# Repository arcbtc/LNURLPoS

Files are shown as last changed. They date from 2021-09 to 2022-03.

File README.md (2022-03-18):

# LNURLPoS

## Cheap, offline(!), DIY bitcoin lightning-network PoS

### for a more up to date version of lnurlpos, checkout <a href="https://github.com/arcbtc/bitcoinPoS">bitcoinPoS</a>

lnurlpos

Lightning-network uses hot wallets and real-world payments are made from phones. The burden of connectivity can be taken away from the point-of-sale and given to the phone.



> <i>Join our <a href="https://t.me/makerbits">telegram support/chat</a>.</i>

> <i>For a traditional PoS experience see my <a href="https://github.com/arcbtc/LNPoS">LNPoS project</a>.</i>

> <i>The manufacturer of the microcontroller used have actually released a specific kit for LNURLPoS! <a href="https://github.com/Xinyuan-LilyGO/T-Display-keyboard">LiLyGos repo</a>.</i>

LNURLPoS uses the LNURL-pay protocol. LNURL-pay allows your lightning-wallet to make a secure request to a server to get a lightning-network invoice. So instead of scanning a massive ugly lightning-network invoice QR, you can scan a lovely little LNURL QR (if you <a href="https://lnurl.fiatjaf.com/codec/">decode</a> an LNURL you'll see its just a URL).



For online stuff I suppose massive QR codes are not an issue, but when fiddling with hardware devices they are. LNURLPoS using the LNURL-pay protocol, it can use a smaller screen for displaying the QR.

### Setup workflow

- LNURLPoS server set up and register PoS in a few clicks on <a href="https://github.com/lnbits/lnbits/">LNbits</a> using the <a href="https://github.com/lnbits/lnbits/tree/master/lnbits/extensions/lnurlpos">LNURLPoS</a> extension
- Copy credentials (including a secret key) from server to the physical LNURLPoS device

### Payment workflow

- Merchant enters amount into LNURLPoS device
- LNURL is generated in device and displayed for scanning (LNURL includes a unique pin encrypted using the secret key shared with the server)
- Customer scans and pays
- When the payment has cleared the customer is sent the decrypted unique pin
- Merchant can compare and verify using the same pin displayed on the lNURLPoS

### Credit/props

Stepan Snigerev for creating beautiful crypto and LNURL encoding functions.

Fiatjafs incredible <a href="https://github.com/lnbits/lnbits/tree/master/lnbits/extensions/offlineshop">OfflineShop</a> extension. LNURLPoS is the same concept, but can run at scale, and is dependent on a device.

<a href="https://www.bleskomat.com/">Belskomat</a> for pironeering the idea of a shared secret for the microcontroller to encrypt data with.

# ⚡⚡⚡⚡⚡⚡ LNURLPoS Tutorial ⚡⚡⚡⚡⚡⚡



### Hardware needed

- <a href="https://www.aliexpress.com/item/33048962331.html">Lilygo TTGO T-Display</a>
- Keypad membrane (these <a href="https://www.aliexpress.com/item/32812109541.html">big</a> ones are easy to find, these <a href="https://www.aliexpress.com/item/1005003263865347.html">smaller</a> ones will be used for workshops by arcbtc).
- <a href="https://www.amazon.co.uk/Sourcingmap-2x40-Pins-Connector-Arduino-Prototype-Black-Silver-Tone/dp/B07DK532DP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">Angled male/male GPIO pins</a>

### Arduino software install

- Download/install latest <a href="https://www.arduino.cc/en/software">Arduino IDE</a>
- Install ESP32 boards, using <a href="https://docs.espressif.com/projects/arduino-esp32/en/latest/installing.html#installing-using-boards-manager">boards manager</a>
- Copy <a href="https://github.com/arcbtc/LNURLPoS/tree/main/LNURLPoS/libraries">these libraries</a> into your Arduino IDE library folder
- Plug in T-Display, from _Tools>Board>ESP32 Boards_ select **TTGO LoRa32 OLED V1**

> _Note: If using MacOS, you will need the CP210x USB to UART Bridge VCP Drivers available here https://www.silabs.com/developers/usb-to-uart-bridge-vcp-drivers_

### LNbits extension

To make things easy (usually a few clicks on things like Raspiblitz), there is an <a href="https://github.com/lnbits/lnbits/tree/master/lnbits/extensions/lnurlpos">LNbits extension</a>.
If you want to make your own stand-alone server software that would be fairly easy to do, by replicating the lnurl.py file in the extennsion.

### Future updates

At the beginning of this article I said "LNURLPoS (currently) only uses LNURL-Pay". The next stage will be for the PoS to also create LNURL-Withdraws, which are essentially faucets. This means merchants can offer refunds, and also sell bitcoin over the counter, which creates an extremely powerful tool for local economies on-ramping and off-ramping from their local fiat currency.

At Adopting Bitcoin in San Salvador I will distribute 40 kits over x2 workshops, so hopefully some locals will start producing, selling and teaching others how to make these useful little units.

---

## Deeper Dive

### LNURL

Much of the innovation that happens on lightning-network uses an additional protocol layer called LNURL.

LNURL is just a bech32 encoded URL string, that is a link to an LNURL server that your lightning wallet can request information from. By your wallet being able to communicate with a server, developers are no longer bound by the _payee-generate-invoice_ workflow. There are many different types of LNURL. LNURLPoS (currently) only uses LNURL-Pay.

This is an LNURL-pay QR code:



This is the data in that QR code:

`LNURL1DP68GURN8GHJ7MRWVF5HGUEWVDHK6TMVDE6HYMRS9ASHQ6F0WCCJ7MRWW4EXCTECXVUQR8PUDZ`

If we decode the LNURL we get this URL:

`https://legend.lnbits.com/lnurlp/api/v1/lnurl/838`

If you do a GET request to the URL this data will be returned (you can test this by just visiting the URL in a browser):

```
{
  "callback": "https://lnbits.com/lnurlp/api/v1/lnurl/cb/838",
  "maxSendable": 10000000000,
  "metadata": "[[\"text/plain\", \"Lovely little QR\"]]",
  "minSendable": 10000,
  "tag": "payRequest"
}
```

When your wallet gets this json it asks you how much you want to send between the `minSendable` and `maxSendable`.

After a moment you get a “payment sent” confirmation and receipt.



So what happened?

When you verify you want to send say 10sats, your wallet sends that data (as a json) to the `callback` URL. The server then generates an invoice for that amount and sends it back to your wallet, which pays it. Once the payment has cleared, the wallet reveals a receipt to you.

### LNURLPoS workflow

LNURLPoS generates and encodes the LNURL in the device, which means we can pass some data in the URL.

The LNURLPoS stores four important pieces of data:

- URL to your LNURL server (we’re using an LNbits install, with dedicated extension)
- PoS ID (Unique ID generated in the LNbits extension)
- Secret (Secret shared with the LNURL server)
- Currency denomination (being offline sats becomes too volatile)

LNURLPoS could use any LNURL server that performs some certain functions, but to make things easy I made an extension in LNbits specifically for LNURLPoS




Once a PoS has been generated the extension gives you this data:

```
String server = "https://lnbits.com";
String posId = "L4aJNiQZyPxCREoB3KXiiU";
String key = "4TPLxRmv82yEFjUgWKdfPh";
String currency = "EUR";
```

The data can then be passed to the device when uploading its software through the Arduino IDE



When an amount is entered into the LNURLPoS, the device generates a unique pin, then encrypts the amount+pin using the shared secret and a nonce. The server endpoint, nonce, encypted data, and PoS ID are built into into the LNURL.

`https://lnbits.com/lnurlpos/api/v1/lnurl/<nonce>/<encrypted-data>/<pos-id>`

`LNURL1DP68GURN8GHJ7MRWVF5HGUEWVDHK6TMVDE6HYMRSDAEJ7CTSDYHHVVF0D3H82UNV9U7XUMMWVDJNUTEUV4HXXUNEWP6X2EPDV3SHGCF79U78QMMN945KG0S2PG6GTWSK`

When that first GET request happens from the wallet, the LNURL server can find the PoS record, fetch its secret use the secret to decrypt the amount+pin. The amount is converted from the fiat currency to sats, and sent back to the wallet as `minSendable` and `maxSendable`.

If the invoice passed to the wallet is paid the customer is given access to the decrypted pin.



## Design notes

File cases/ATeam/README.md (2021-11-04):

## ATeam Edition case
Recycle the T-Display case, as with the smaller keypad it all fits together perfectly. See <a href="https://twitter.com/arcbtc/status/1442511015669809152">demo</a>

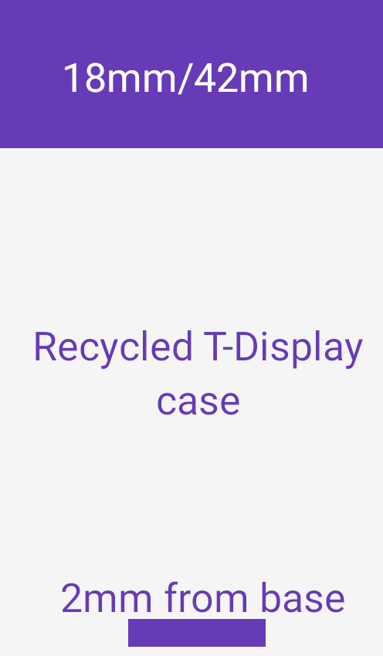
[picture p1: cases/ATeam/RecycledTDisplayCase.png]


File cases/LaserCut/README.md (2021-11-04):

## Laser Cut CAses for LNURLPoS

There are 2 lightburn designs for cases depending on membrane keypads. Designs use layered 3mm acrylic and M4 nuts/bolts <br/>(Blue = fill/engrave 1.5mm depth, Black = cut)

<p align="center">

</p>
<br/><br/>
Laser cutters are cheap now and should be part of every makers arsenal, these examples were cut on £200 NEJE Master2s 20W, alternatively there are plenty of laser engraving/cutting companies.
<br/><br/>

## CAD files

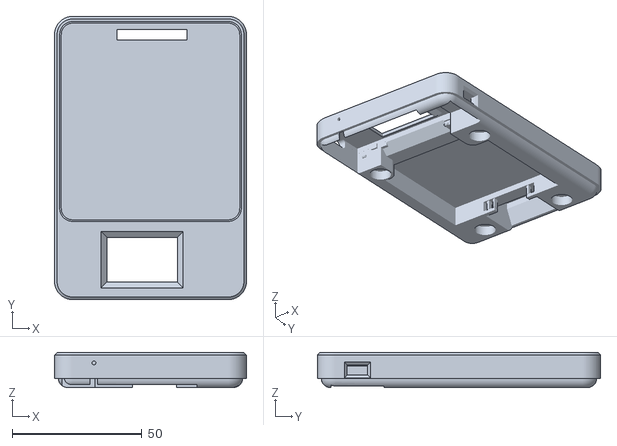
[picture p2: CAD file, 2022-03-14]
cases/3d printed/4 x 4 keypad/LNURLPoS case top with supports.stl
74.0 x 109.1 x 13.5

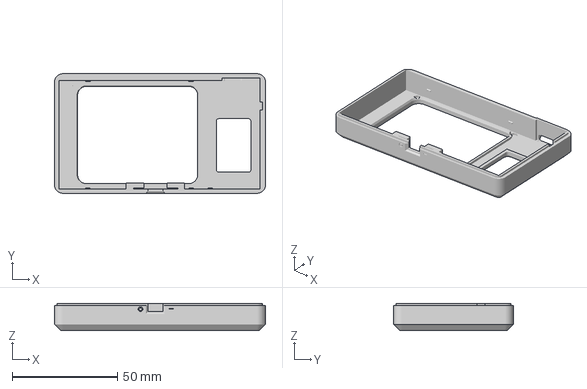
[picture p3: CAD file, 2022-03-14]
cases/3d printed/LilyGo T-Display Keyboard/LilyGo keyboard case top larger hole.3mf
100.2 x 56.8 x 13.0 mm

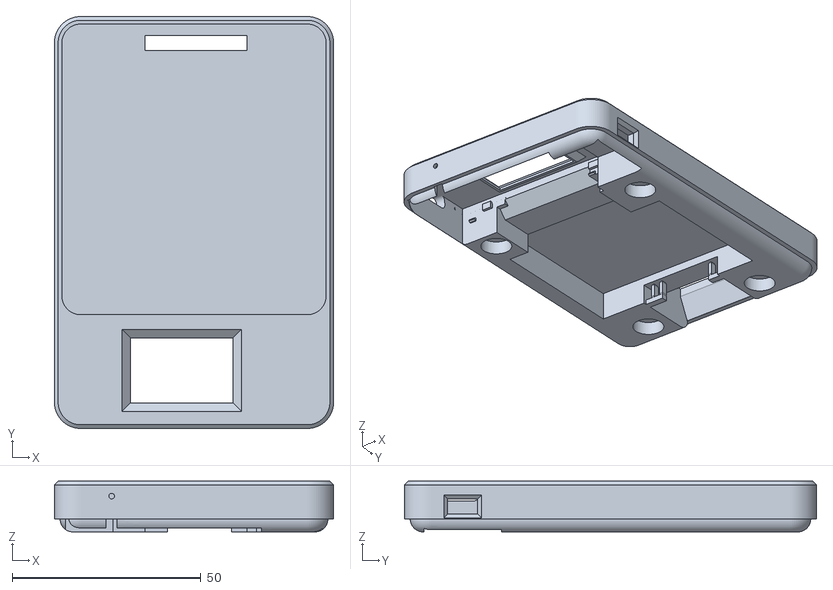
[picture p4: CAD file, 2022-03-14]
cases/3d printed/4 x 4 keypad/LNURLPoS case top.stl
74.0 x 109.1 x 13.5

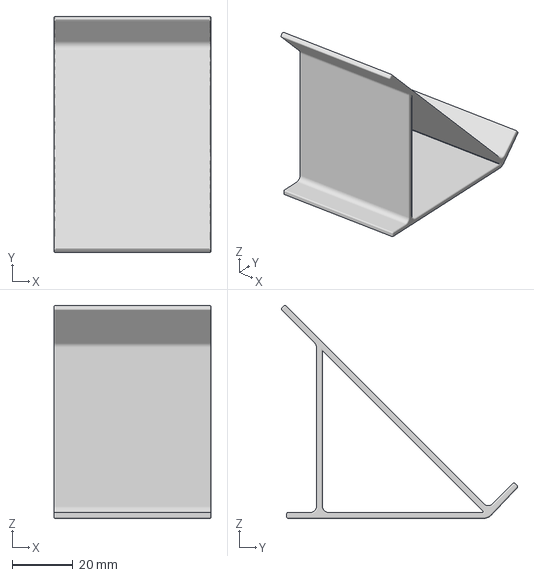
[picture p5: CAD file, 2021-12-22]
cases/3d printed/LilyGo T-Display Keyboard/Stand.3mf
51.7 x 77.9 x 70.2 mm

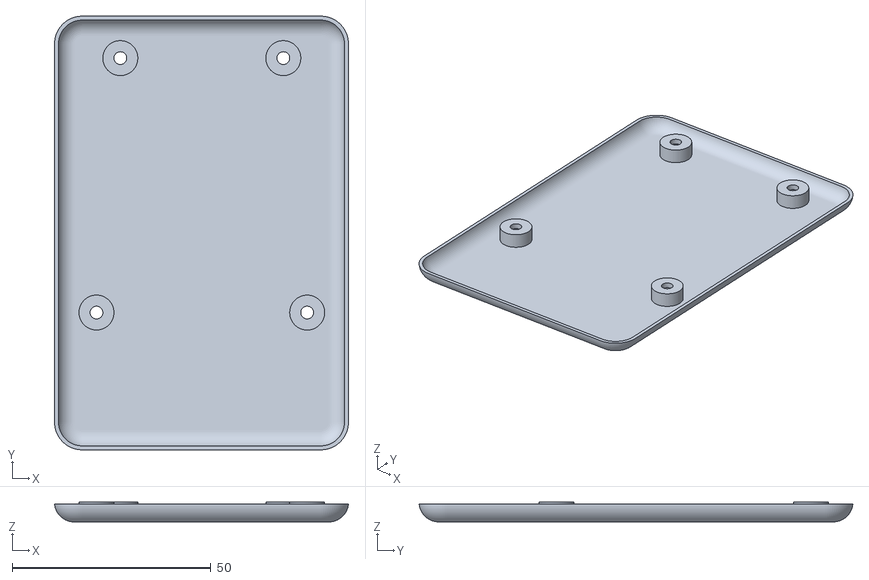
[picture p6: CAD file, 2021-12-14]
cases/3d printed/4 x 4 keypad/LNURLPoS case bottom.stl
73.9 x 109.1 x 5.00

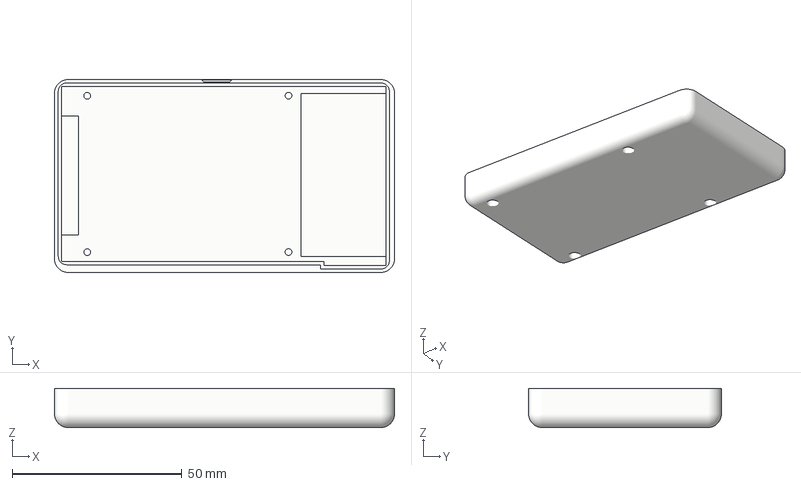
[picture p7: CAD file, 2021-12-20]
cases/3d printed/LilyGo T-Display Keyboard/LilyGo keyboard case bottom.3mf
100.2 x 56.9 x 11.5 mm

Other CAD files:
cases/3d printed/LilyGo T-Display Keyboard/LilyGo keyboard case top.3mf

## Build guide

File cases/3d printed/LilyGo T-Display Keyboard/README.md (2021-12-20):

# 3D Printed Cases for LNURLPoS with LilyGo T-Display Keyboard

These 3D print files will print a case for the LilyGo T-Display Keyboard https://aliexpress.com/item/1005003534734992.html.

The keyboard will need to be dismantled to fit it into the case.

When reassembling, the screws that held the back plate on to the keyboard, go through the back of the case as well as the keyboard rear plate to hold the case together.

Use these switches if you want to include a battery for untethered power https://www.amazon.co.uk/gp/product/B00OK9FAUW/

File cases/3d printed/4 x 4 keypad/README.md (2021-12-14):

# 3D Printed Cases for LNURLPoS

These 3D print files will print a case for the LNURLPoS device

There is space inside the case for a small battery, a switch and the TTGO display.

These switches will fit in the case. They should be hot glued into place until we have a better solution.

https://www.amazon.co.uk/gp/product/B00OK9FAUW/

## Printing

The stl/m3u files print best when oriented with the keypad side of the top and the outside of the bottom flat on the print bed. 

Use printing support everywhere with 20% infil.

## Additional Parts

4 x M3 x 5mm screws are required to attach the base to the top.

4 x 5.6mm adhesive rubber feet stop the case sliding around on a work surface - https://www.ebay.co.uk/itm/192563250638

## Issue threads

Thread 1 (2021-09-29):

'QRCode' was not declared in this scope?

HamishMacEwan, 2021-09-29:
Hi,

I've checked that I followed the instructions and I have Googled for this error, but none of the results seem conclusive or apply.

It's my first time with the Arduino IDE, but it seems to have found and I've installed the libraries required, and though I'm still waiting for the hardware, thought I'd get about preparing for its arrival by verifying, by compilation, the set up.

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

If there's any additional information required, please advise.

arcbtc, 2021-09-29:
Thanks Hamish!
You need to copy the libraries into you arduino core libraries folder.
Open File>Examples>Basic>Blink
Go to Sketch>Show sketch foler
Now you have your Arduino install folder, go down a few levels
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
Then place the projects libraries in the core libraries folder:
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
Should be gravy now!

HamishMacEwan, 2021-09-29:
Thanks very much for the instructions.  It has led to a long and frustrating encounter with Windows 10 permissions.

The directory for the installation as derived from your guidance above is:

`C:\Program Files\WindowsApps\ArduinoLLC.ArduinoIDE_1.8.51.0_x86__mdqgnx93n4wtt\libraries`

All attempts to copy the files there have been met with refusal and my permissions foo has not been very successful, though I do now "own" the WindowsApps folder, to no useful effect.

Currently I have the additional libraries in a more accessible folder and for all but the QRCode library that appears to be working:

```
Using library SPI at version 2.0.0 in folder: C:\Users\User\OneDrive\Documents - Old\ArduinoData\packages\esp32\hardware\esp32\2.0.0\libraries\SPI

Using library TFT_eSPI at version 2.2.20 in folder: C:\Users\User\OneDrive\Documents - Old\Arduino\libraries\TFT_eSPI

Using library FS at version 2.0.0 in folder: C:\Users\User\OneDrive\Documents - Old\ArduinoData\packages\esp32\hardware\esp32\2.0.0\libraries\FS

Using library SPIFFS at version 2.0.0 in folder: C:\Users\User\OneDrive\Documents - Old\ArduinoData\packages\esp32\hardware\esp32\2.0.0\libraries\SPIFFS

Using library Keypad at version 3.1.1 in folder: C:\Users\User\OneDrive\Documents - Old\Arduino\libraries\Keypad

Using library uBitcoin at version 0.1.2 in folder: C:\Users\User\OneDrive\Documents - Old\Arduino\libraries\uBitcoin
```

There is a collision at:
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

That is another `qrcode.h` at `C:\Users\User\OneDrive\Documents - Old\ArduinoData\packages\esp32\hardware\esp32\2.0.0\tools\sdk\esp32\include\qrcode\include` which is fulfilling the `#include` though not usefully.

Is there are way to specify exactly the order of paths to search or include a path in the `#include` syntax?

babysnakeum, 2021-10-01:
FYI I'm observing the same issue on mac, even after copying the libraries into arduinos core libraries folder

HamishMacEwan, 2021-10-02:
```
Arduino: 1.8.16 (Windows 10), Board: "TTGO LoRa32-OLED V1, 80MHz, 921600, None"

c:/users/user/appdata/local/arduino15/packages/esp32/tools/xtensa-esp32-elf-gcc/gcc8_4_0-esp-2021r1/bin/../lib/gcc/xtensa-esp32-elf/8.4.0/../../../../xtensa-esp32-elf/bin/ld.exe: C:\Users\User\AppData\Local\Arduino15\packages\esp32\hardware\esp32\2.0.0/tools/sdk/esp32/lib\libwpa_supplicant.a(crypto_mbedtls.c.obj): in function `hmac_sha256':

/home/runner/work/esp32-arduino-lib-builder/esp32-arduino-lib-builder/esp-idf/components/wpa_supplicant/src/crypto/crypto_mbedtls.c:254: multiple definition of `hmac_sha256'; libraries\uBitcoin\utility\trezor\hmac.c.o:C:\Program Files (x86)\arduino-1.8.16\libraries\uBitcoin\src\utility\trezor/hmac.c:67: first defined here

collect2.exe: error: ld returned 1 exit status

exit status 1

Error compiling for board TTGO LoRa32-OLED V1.
```

Different error, so one thing is solved.

ShelbyApp, 2021-11-08:
I've put the QRCode library in every libraries folder that exists and still have this problem.

I can even click Sketch->Include Library->QRCode which includes <qrcode.h> and still get the problem

I can access the QRCode example through the Arduino software and that won't compile either (Same error)

Seems like there is a bigger problem going on?

citizenanalog, 2021-11-08:
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

I had to switch to MacOS and had to add the libraries manually but eventually got it to work. Still no luck on Ubuntu.

ShelbyApp, 2021-11-08:
I moved the QRCode to the local folder with "qrcode.h" and got it to work

but now I am getting the redundant sha256 error now  :(  Did you have that one?

c:/users/jason/appdata/local/arduino15/packages/esp32/tools/xtensa-esp32-elf-gcc/gcc8_4_0-esp-2021r1/bin/../lib/gcc/xtensa-esp32-elf/8.4.0/../../../../xtensa-esp32-elf/bin/ld.exe: C:\Users\Jason\Documents\Arduino\hardware\espressif\esp32/tools/sdk/esp32/lib\libwpa_supplicant.a(crypto_mbedtls.c.obj): in function `hmac_sha256':

/Users/ficeto/Desktop/ESP32/ESP32S2/esp-idf-public/components/wpa_supplicant/src/crypto/crypto_mbedtls.c:254: multiple definition of `hmac_sha256'; libraries\uBitcoin\utility\trezor\hmac.c.o:C:\Program Files (x86)\Arduino\libraries\uBitcoin\src\utility\trezor/hmac.c:67: first defined here
collect2.exe: error: ld returned 1 exit status

ShelbyApp, 2021-11-08:
DING DING DING

If you go to utilities/trezor/hmac.c

There are 2 definitions of the following, just delete 1 and should be good to go

void hmac_sha256(const uint8_t *key, const uint32_t keylen, const uint8_t *msg, const uint32_t msglen, uint8_t *hmac)
{
	static CONFIDENTIAL HMAC_SHA256_CTX hctx;
	hmac_sha256_Init(&hctx, key, keylen);
	hmac_sha256_Update(&hctx, msg, msglen);
	hmac_sha256_Final(&hctx, hmac);
}

claytantor, 2021-11-21:
so I think I _may_ know what the problem is, `QRCode` as a directory name instead of all lower case `qrcode` to match the import may be an issue with my version of the compiler finding the import of `qrcode.h`. I made my library name all lower case and it seems to be properly importing now.

trbouma, 2021-12-21:
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

Hi I successfully got to this point then encountered this error below. I am running Ubuntu 20

Arduino: 1.8.18 (Linux), Board: "TTGO LoRa32-OLED V1, 80MHz, 921600, None"

Traceback (most recent call last):
  File "/home/trbouma/.arduino15/packages/esp32/tools/esptool_py/3.1.0/esptool.py", line 38, in <module>
    import serial
ImportError: No module named serial
exit status 1
Error compiling for board TTGO LoRa32-OLED V1.

This report would have more information with
"Show verbose output during compilation"
option enabled in File -> Preferences.

Closed 2021-12-30.

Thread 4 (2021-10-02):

Connecting a Lightning Network PoS to LoRaWAN

tobias-kaiser, 2021-10-02:
Interesting work. I think it's a good step towards offline payments, but it still requires the customer to have connectivity. I'm looking for a system that enables payments in the case of an emergency, such as a large-scale blackout. LoRaWAN networks (e.g. Helium) would be a perfect technology to create a fail-safe method for connecting, since these devices don't require much power and can easily be kept online by emergency generators.

So my idea would be a PoS that is connected to LoRaWAN and does not require the customer to have connectivity. The payment workflow would then look like this:

1. The merchant enters the payment amount and creates a LN invoice.
2. The merchant sends the invoice to the customer, who signs it and sends the signed message back to the PoS.
3. The PoS uses its LoRaWAN connectivity to send the signed message off.

I'm wondering if this is somehow possible?

arcbtc, 2021-11-04:
Probably, although you would have to get wallets to implement, which would be tricky.
The payer could create an LNURL-withdraw offline, give it to the merchant who sends it over lora, then gets a confirmation back when paid, but again you would need the customers to be able to mint LNURL-Withdraws, a javacard system could do such magic

Closed 2021-12-30.

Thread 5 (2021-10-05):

Using a clock chip instead of a screen

sturles, 2021-10-05:
I have an idea of how to make this even cheaper by replacing the display with a clock chip (a cheap RTC).

Let the URL contain an encrypted secret, and let the server add a timestamp to that secret using the current time and some simple maths (xor or similar).  Other information may be encoded in as well.  The result is returned as a PIN. User enters PIN, timestamp is removed by XOR with the device's time (use 30 second or minute intervals and check values for a few minutes back and forth) and compare the resulting PIN with the fixed PIN on the device.  The device can even correct it's own time if it consistently gets PINs based on time in advance or in the past.

Other information may be coded in as well.

Example, a very simple slow car charger.  Price is 100 sat per hour, maximum 8 hours:

1. User scans fixed QR code with LNURLp and encrypted secret s.
2. User pays 200 sat for 2 hours.
3. Server decrypt s and xor decrypted s with encoded current time and 2 for 200 sat.
4. Server returns PIN.
5. User enters PIN.
6. PoS terminal removes time and secret and check the result for valid values (1-8).
7. In the first or few attempts it will get the valid value 2 and close the relay powering the charger for 2 hours.
8. If all the 10 past PINs indicated a time in the future or past, advance or revert the RTC by one minute.

The time and amount must be encoded in a way that minimizes the chance of a wrong amount becoming valid within a reasonable time scope.

arcbtc, 2021-11-04:
Nice. Changed the name to reflect the idea better.

So how would you indicate a successful pin was entered, an LED?

Closed 2021-12-30.

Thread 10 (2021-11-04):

Awesome work!

brihogan, 2021-11-04:
This isn’t an issue. Just not sure if I can send messages in GitHub. Really just wanted to say thank you for such a cool project. You’re doing such cool stuff and it’s so cool that you’re being open about it and letting everyone have the code and even show them in a video how it all works. So cool!

I had a pet project a few years back related to Ninja Warrior-type timing for a local business. It was such a fun hobby and seeing your work makes me get back that excitement. Now my mind is racing thinking about doing something with your project with something like an arcade, vending machine, art-piece, etc. Those things have been hampered in my mind due to lack of internet connection in some locations (and paying for cell access was not worth it).

I think with your system the vendor has to look at a customer’s phone to see the pin code, right? Could that pin code be replaced by a QR code and then the arcade/vending-machine has a camera that confirms the code? That way everything could be totally unmanned, right?

Anyway, now I have to think up a project. My wife will probably be mad at you. :)

Thanks again!

arcbtc, 2021-11-24:
Absolutely. I have been speaking with an excellent/small/cheap vending machine supplier in China to make such a thing possible. As soon as it arrives I will release a tut

EastSideTony, 2021-12-14:
Excellent

arcbtc, 2021-12-30:
https://github.com/arcbtc/LNURLVend

Closed 2021-12-30.

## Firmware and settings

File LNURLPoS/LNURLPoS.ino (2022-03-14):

/////////////////////////////////////////////////////////////////////////////////
//////WARNING! WE ADVISE SWITCHING TO https://github.com/arcbtc/bitcoinPoS///////
/////////////////////////////////////////////////////////////////////////////////

#include "SPI.h"
#include "FS.h"
#include "TFT_eSPI.h"
#include <Keypad.h>
#include <string.h>
#include "qrcoded.h"
#include "Bitcoin.h"
#include <Hash.h>
#include <Conversion.h>
#include <WiFi.h>
#include "esp_adc_cal.h"
#include "SPIFFS.h"


////////////////////////////////////////////////////////
////////CHANGE! USE LNURLPoS EXTENSION IN LNBITS////////
////////////////////////////////////////////////////////

String baseURL = "https://legend.lnbits.com/lnurlpos/api/v1/lnurl/UZsLkBSzdDqEFgc3RAs8rj";
String key = "UzhUjUGFvEtJRaVSpxxNCa";
String currency = "USD";

//////////////KEYPAD///////////////////
bool isLilyGoKeyboard = false;

//////////////SLEEP SETTINGS///////////////////
bool isSleepEnabled = true;
int sleepTimer = 30; // Time in seconds before the device goes to sleep

//////////////QR DISPLAY BRIGHTNESS///////////////////
int qrScreenBrightness = 180; // 0 = min, 255 = max

//////////////BATTERY///////////////////
const bool shouldDisplayBatteryLevel = false; // Display the battery level on the display?
const float batteryMaxVoltage = 4.2;          // The maximum battery voltage. Used for battery percentage calculation
const float batteryMinVoltage = 3.73;         // The minimum battery voltage that we tolerate before showing the warning

////////////////////////////////////////////////////////
////Note: See lines 75, 97, to adjust to keypad size////
////////////////////////////////////////////////////////

//////////////VARIABLES///////////////////
String dataId = "";
bool paid = false;
bool shouldSaveConfig = false;
bool down = false;
const char *spiffcontent = "";
String spiffing;
String lnurl;
String choice;
String payhash;
String key_val;
String cntr = "0";
String inputs;
int keysdec;
int keyssdec;
float temp;
String fiat;
float satoshis;
String nosats;
float conversion;
String virtkey;
String payreq;
int randomPin;
bool settle = false;
String preparedURL;
RTC_DATA_ATTR int bootCount = 0;
long timeOfLastInteraction = millis();
bool isPretendSleeping = false;

#include "MyFont.h"

#define BIGFONT &FreeMonoBold24pt7b
#define MIDBIGFONT &FreeMonoBold18pt7b
#define MIDFONT &FreeMonoBold12pt7b
#define SMALLFONT &FreeMonoBold9pt7b
#define TINYFONT &TomThumb
#define FORMAT_SPIFFS_IF_FAILED true

TFT_eSPI tft = TFT_eSPI();
SHA256 h;

// QR screen colours
uint16_t qrScreenBgColour = tft.color565(qrScreenBrightness, qrScreenBrightness, qrScreenBrightness);

//////////////KEYPAD///////////////////

const byte rows = 4; //four rows
const byte cols = 3; //three columns
char keys[rows][cols] = {
    {'1', '2', '3'},
    {'4', '5', '6'},
    {'7', '8', '9'},
    {'*', '0', '#'}};

//Big keypad setup
//byte rowPins[rows] = {12, 13, 15, 2}; //connect to the row pinouts of the keypad
//byte colPins[cols] = {17, 22, 21}; //connect to the column pinouts of the keypad

//LilyGO T-Display-Keyboard
//byte rowPins[rows] = {21, 27, 26, 22}; //connect to the row pinouts of the keypad
//byte colPins[cols] = {33, 32, 25}; //connect to the column pinouts of the keypad

// 4 x 4 keypad setup
//byte rowPins[rows] = {21, 22, 17, 2}; //connect to the row pinouts of the keypad
//byte colPins[cols] = {15, 13, 12}; //connect to the column pinouts of the keypad

//Small keypad setup
byte rowPins[rows] = {21, 22, 17, 2}; //connect to the row pinouts of the keypad
byte colPins[cols] = {15, 13, 12};    //connect to the column pinouts of the keypad

Keypad keypad = Keypad(makeKeymap(keys), rowPins, colPins, rows, cols);
int checker = 0;
char maxdig[20];

//////////////MAIN///////////////////

void setup(void)
{
  Serial.begin(115200);
  pinMode(4, OUTPUT);
  digitalWrite(4, HIGH);
  btStop();
  WiFi.mode(WIFI_OFF);
  h.begin();
  tft.begin();

  //Set to 3 for bigger keypad
  tft.setRotation(1);

  Serial.println("mounting FS...");
    
  while(!SPIFFS.begin(FORMAT_SPIFFS_IF_FAILED)){
    Serial.println("failed to mount FS");
    delay(200);
  }

  loadConfig();  

  if(bootCount == 0)
  {
    logo();
    delay(3000);
  }
  else
  {
    wakeAnimation();
  }
  ++bootCount;
  Serial.println("Boot count" + bootCount);
}

void loop()
{
  digitalWrite(4, HIGH);
  maybeSleepDevice();
  inputs = "";
  settle = false;
  displaySats();
  bool cntr = false;

  while (cntr != true)
  {
    maybeSleepDevice();
    displayBatteryVoltage(false);
    char key = keypad.getKey();
    if (key != NO_KEY)
    {
      isPretendSleeping = false;
      timeOfLastInteraction = millis();
      virtkey = String(key);
      if (virtkey == "#")
      {
        makeLNURL();
        qrShowCode();
        int counta = 0;
        while (settle != true)
        {
          virtkey = String(keypad.getKey());
          if (virtkey == "*")
          {
            timeOfLastInteraction = millis();
            tft.fillScreen(TFT_BLACK);
            settle = true;
            cntr = true;
          }
          else if (virtkey == "#")
          {
            timeOfLastInteraction = millis();
            showPin();
          }
          // Handle screen brighten on QR screen
          else if (virtkey == "1")
          {
            timeOfLastInteraction = millis();
            adjustQrBrightness("increase");
          }
          // Handle screen dim on QR screen
          else if (virtkey == "4")
          {
            timeOfLastInteraction = millis();
            adjustQrBrightness("decrease");
          }
        }
      }
      else if (virtkey == "*")
      {
        tft.fillScreen(TFT_BLACK);
        tft.setCursor(0, 0);
        tft.setTextColor(TFT_WHITE);
        key_val = "";
        inputs = "";
        nosats = "";
        virtkey = "";
        cntr = "2";
      }
      displaySats();
    }
  }
}

void adjustQrBrightness(String direction)
{
  if (direction == "increase" && qrScreenBrightness >= 0)
  {
    qrScreenBrightness = qrScreenBrightness + 25;
    if (qrScreenBrightness > 255)
    {
      qrScreenBrightness = 255;
    }
  }
  else if (direction == "decrease" && qrScreenBrightness <= 30)
  {
    qrScreenBrightness = qrScreenBrightness - 5;
  }
  else if (direction == "decrease" && qrScreenBrightness <= 255)
  {
    qrScreenBrightness = qrScreenBrightness - 25;
  }

  if (qrScreenBrightness < 4)
  {
    qrScreenBrightness = 4;
  }

  qrScreenBgColour = tft.color565(qrScreenBrightness, qrScreenBrightness, qrScreenBrightness);
  qrShowCode();

  File configFile = SPIFFS.open("/config.txt", "w");
  configFile.print(String(qrScreenBrightness));
  configFile.close();
}

///////////DISPLAY///////////////

void qrShowCode()
{
  tft.fillScreen(qrScreenBgColour);
  lnurl.toUpperCase();
  const char *lnurlChar = lnurl.c_str();
  QRCode qrcoded;
  uint8_t qrcodeData[qrcode_getBufferSize(20)];
  qrcode_initText(&qrcoded, qrcodeData, 6, 0, lnurlChar);
  for (uint8_t y = 0; y < qrcoded.size; y++)
  {
    // Each horizontal module
    for (uint8_t x = 0; x < qrcoded.size; x++)
    {
      if (qrcode_getModule(&qrcoded, x, y))
      {
        tft.fillRect(60 + 3 * x, 5 + 3 * y, 3, 3, TFT_BLACK);
      }
      else
      {
        tft.fillRect(60 + 3 * x, 5 + 3 * y, 3, 3, qrScreenBgColour);
      }
    }
  }
}

void showPin()
{
  tft.fillScreen(TFT_BLACK);
  tft.setTextColor(TFT_WHITE, TFT_BLACK);
  tft.setFreeFont(SMALLFONT);
  tft.setCursor(30, 25);
  tft.println("PAYMENT PROOF PIN");
  tft.setCursor(60, 80);
  tft.setTextColor(TFT_PURPLE, TFT_BLACK);
  tft.setFreeFont(BIGFONT);
  tft.println(randomPin);
}

void displaySats()
{
  tft.fillScreen(TFT_BLACK);
  tft.setTextColor(TFT_WHITE, TFT_BLACK); // White characters on black background
  tft.setFreeFont(MIDFONT);
  tft.setCursor(0, 20);
  tft.println("AMOUNT THEN #");
  tft.setCursor(60, 130);
  tft.setFreeFont(SMALLFONT);
  tft.println("TO RESET PRESS *");

  inputs += virtkey;

  tft.setFreeFont(MIDFONT);
  tft.setCursor(0, 80);
  tft.print(String(currency) + ":");
  tft.setFreeFont(MIDBIGFONT);
  tft.setTextColor(TFT_GREEN, TFT_BLACK);

  if (currency != "sats")
  {
    float amount = float(inputs.toInt()) / 100;
    tft.println(amount);
  }
  else
  {
    int amount = inputs.toInt();
    tft.println(amount);
  }

  displayBatteryVoltage(true);
  delay(50);
  virtkey = "";
}

void logo()
{
  tft.fillScreen(TFT_BLACK);
  tft.setTextColor(TFT_WHITE, TFT_BLACK); // White characters on black background
  tft.setFreeFont(BIGFONT);
  tft.setCursor(7, 70);  // To be compatible with Adafruit_GFX the cursor datum is always bottom left
  tft.print("LNURLPoS"); // Using tft.print means text background is NEVER rendered

  tft.setTextColor(TFT_PURPLE, TFT_BLACK); // White characters on black background
  tft.setFreeFont(SMALLFONT);
  tft.setCursor(42, 90);          // To be compatible with Adafruit_GFX the cursor datum is always bottom left
  tft.print("Powered by LNbits"); // Using tft.print means text background is NEVER rendered
}

void to_upper(char *arr)
{
  for (size_t i = 0; i < strlen(arr); i++)
  {
    if (arr[i] >= 'a' && arr[i] <= 'z')
    {
      arr[i] = arr[i] - 'a' + 'A';
    }
  }
}

long lastBatteryUpdate = millis();
int batteryLevelUpdatePeriod = 10; // update every X seconds
/**
 * Display the battery voltage
 */
void displayBatteryVoltage(bool forceUpdate)
{
  long currentTime = millis();
  if (
      (shouldDisplayBatteryLevel &&
       (currentTime > (lastBatteryUpdate + batteryLevelUpdatePeriod * 1000)) &&
       !isPoweredExternally()) ||
      (shouldDisplayBatteryLevel && forceUpdate && !isPoweredExternally()))
  {
    lastBatteryUpdate = currentTime;
    bool showBatteryVoltage = false;
    float batteryCurV = getInputVoltage();
    float batteryAllowedRange = batteryMaxVoltage - batteryMinVoltage;
    float batteryCurVAboveMin = batteryCurV - batteryMinVoltage;

    int batteryPercentage = (int)(batteryCurVAboveMin / batteryAllowedRange * 100);

    if (batteryPercentage > 100)
    {
      batteryPercentage = 100;
    }

    int textColour = TFT_GREEN;
    if (batteryPercentage > 70)
    {
      textColour = TFT_GREEN;
    }
    else if (batteryPercentage > 30)
    {
      textColour = TFT_YELLOW;
    }
    else
    {
      textColour = TFT_RED;
    }

    tft.setTextColor(textColour, TFT_BLACK);
    tft.setFreeFont(SMALLFONT);

    int textXPos = 195;
    if (batteryPercentage < 100)
    {
      textXPos = 200;
    }

    // Clear the area of the display where the battery level is shown
    tft.fillRect(textXPos - 2, 0, 50, 20, TFT_BLACK);
    tft.setCursor(textXPos, 16);

    // Is the device charging?
    if (isPoweredExternally())
    {
      tft.print("CHRG");
    }
    // Show the current voltage
    if (batteryPercentage > 10)
    {
      tft.print(String(batteryPercentage) + "%");
    }
    else
    {
      tft.print("LO!");
    }

    if (showBatteryVoltage)
    {
      tft.setFreeFont(SMALLFONT);
      tft.setCursor(155, 36);
      tft.print(String(batteryCurV) + "v");
    }
  }
}

/**
 * Check whether the device should be put to sleep and put it to sleep
 * if it should
 */
void maybeSleepDevice()
{
  if (isSleepEnabled && !isPretendSleeping)
  {
    long currentTime = millis();
    if (currentTime > (timeOfLastInteraction + sleepTimer * 1000))
    {
      sleepAnimation();
      // The device wont charge if it is sleeping, so when charging, do a pretend sleep
      if (isPoweredExternally())
      {
        Serial.println("Pretend sleep now");
        isPretendSleeping = true;
        tft.fillScreen(TFT_BLACK);
      }
      else
      {
        if (isLilyGoKeyboard)
        {
          esp_sleep_enable_ext0_wakeup(GPIO_NUM_33, 1); //1 = High, 0 = Low
        }
        else
        {
          //Configure Touchpad as wakeup source
          touchAttachInterrupt(T3, callback, 40);
          esp_sleep_enable_touchpad_wakeup();
        }
        Serial.println("Going to sleep now");
        esp_deep_sleep_start();
      }
    }
  }
}

void callback()
{
}

/**
 * Awww. Show the go to sleep animation
 */
void sleepAnimation()
{
  printSleepAnimationFrame("(o.o)", 500);
  printSleepAnimationFrame("(-.-)", 500);
  printSleepAnimationFrame("(-.-)z", 250);
  printSleepAnimationFrame("(-.-)zz", 250);
  printSleepAnimationFrame("(-.-)zzz", 250);
  digitalWrite(4, LOW);
}

void wakeAnimation()
{
  printSleepAnimationFrame("(-.-)", 100);
  printSleepAnimationFrame("(o.o)", 200);
  tft.fillScreen(TFT_BLACK);
}

/**
 * Print the line of the animation
 */
void printSleepAnimationFrame(String text, int wait)
{
  tft.fillScreen(TFT_BLACK);
  tft.setCursor(5, 80);
  tft.setTextColor(TFT_WHITE, TFT_BLACK);
  tft.setFreeFont(BIGFONT);
  tft.println(text);
  delay(wait);
}

/**
 * Get the voltage going to the device
 */
float getInputVoltage()
{
  delay(100);
  uint16_t v1 = analogRead(34);
  return ((float)v1 / 4095.0f) * 2.0f * 3.3f * (1100.0f / 1000.0f);
}

/**
 * Does the device have external or internal power?
 */
bool isPoweredExternally()
{
  float inputVoltage = getInputVoltage();
  if (inputVoltage > 4.5)
  {
    return true;
  }
  else
  {
    return false;
  }
}

/**
 * Load stored config values
 */
void loadConfig() {
  File file = SPIFFS.open("/config.txt");
   spiffing = file.readStringUntil('\n');
  String tempQrScreenBrightness = spiffing.c_str();
  int tempQrScreenBrightnessInt = tempQrScreenBrightness.toInt();
  Serial.println("spiffcontent " + String(tempQrScreenBrightnessInt));
  file.close();

  if(tempQrScreenBrightnessInt && tempQrScreenBrightnessInt > 3) {
    qrScreenBrightness = tempQrScreenBrightnessInt;
  }
  Serial.println("qrScreenBrightness from config " + String(qrScreenBrightness));
  qrScreenBgColour = tft.color565(qrScreenBrightness, qrScreenBrightness, qrScreenBrightness);
}

//////////LNURL AND CRYPTO///////////////

void makeLNURL()
{
  randomPin = random(1000, 9999);
  byte nonce[8];
  for (int i = 0; i < 8; i++)
  {
    nonce[i] = random(256);
  }
  byte payload[51]; // 51 bytes is max one can get with xor-encryption
  size_t payload_len = xor_encrypt(payload, sizeof(payload), (uint8_t *)key.c_str(), key.length(), nonce, sizeof(nonce), randomPin, inputs.toInt());
  preparedURL = baseURL + "?p=";
  preparedURL += toBase64(payload, payload_len, BASE64_URLSAFE | BASE64_NOPADDING);
  Serial.println(preparedURL);
  char Buf[200];
  preparedURL.toCharArray(Buf, 200);
  char *url = Buf;
  byte *data = (byte *)calloc(strlen(url) * 2, sizeof(byte));
  size_t len = 0;
  int res = convert_bits(data, &len, 5, (byte *)url, strlen(url), 8, 1);
  char *charLnurl = (char *)calloc(strlen(url) * 2, sizeof(byte));
  bech32_encode(charLnurl, "lnurl", data, len);
  to_upper(charLnurl);
  lnurl = charLnurl;
  Serial.println(lnurl);
}

/*
 * Fills output with nonce, xored payload, and HMAC.
 * XOR is secure for data smaller than the key size (it's basically one-time-pad). For larger data better to use AES.
 * Maximum length of the output in XOR mode is 1+1+nonce_len+1+32+8 = nonce_len+43 = 51 for 8-byte nonce.
 * Payload contains pin, currency byte and amount. Pin and amount are encoded as compact int (varint).
 * Currency byte is '$' for USD cents, 's' for satoshi, 'E' for euro cents.
 * Returns number of bytes written to the output, 0 if error occured.
 */
int xor_encrypt(uint8_t *output, size_t outlen, uint8_t *key, size_t keylen, uint8_t *nonce, size_t nonce_len, uint64_t pin, uint64_t amount_in_cents)
{
  // check we have space for all the data:
  // <variant_byte><len|nonce><len|payload:{pin}{amount}><hmac>
  if (outlen < 2 + nonce_len + 1 + lenVarInt(pin) + 1 + lenVarInt(amount_in_cents) + 8)
  {
    return 0;
  }
  int cur = 0;
  output[cur] = 1; // variant: XOR encryption
  cur++;
  // nonce_len | nonce
  output[cur] = nonce_len;
  cur++;
  memcpy(output + cur, nonce, nonce_len);
  cur += nonce_len;
  // payload, unxored first - <pin><currency byte><amount>
  int payload_len = lenVarInt(pin) + 1 + lenVarInt(amount_in_cents);
  output[cur] = (uint8_t)payload_len;
  cur++;
  uint8_t *payload = output + cur;                                 // pointer to the start of the payload
  cur += writeVarInt(pin, output + cur, outlen - cur);             // pin code
  cur += writeVarInt(amount_in_cents, output + cur, outlen - cur); // amount
  cur++;
  // xor it with round key
  uint8_t hmacresult[32];
  SHA256 h;
  h.beginHMAC(key, keylen);
  h.write((uint8_t *)"Round secret:", 13);
  h.write(nonce, nonce_len);
  h.endHMAC(hmacresult);
  for (int i = 0; i < payload_len; i++)
  {
    payload[i] = payload[i] ^ hmacresult[i];
  }
  // add hmac to authenticate
  h.beginHMAC(key, keylen);
  h.write((uint8_t *)"Data:", 5);
  h.write(output, cur);
  h.endHMAC(hmacresult);
  memcpy(output + cur, hmacresult, 8);
  cur += 8;
  // return number of bytes written to the output
  return cur;
}

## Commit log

2021-09-16 Added acrylic case design
2021-09-26 Organised case folder
2021-11-04 Added cases
    [Case bottom.3mf, Case bottom.stl, Case top.3mf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]
2021-11-09 Updated case for better ribbon position. Fixed link to switches in cases/3d printings/README.md
    [Case top.3mf, Case top.stl]
2021-11-10 Made case top holes smaller for improved self-tapping screw purchase
    [Case top.3mf, Case top.stl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]
2021-11-10 Updated 3d printed case. Increased battery bay area
    [LNURLPoS case top.3mf, LNURLPoS case top.stl]
2021-11-12 Updated screw hole size in 3d printed case base
    [LNURLPoS case bottom.3mf, LNURLPoS case bottom.stl, LNURLPoS case top.3mf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]
2021-11-14 Updated case
2021-12-14 Added support for screen brightness control via 1 and 4 keys on QR code display. Improves device use in low light envrionemtns
2021-12-14 Fix bug that regenerated passcode when adjustung brightness and small refactor of adjustQrBrightness
    [LNURLPoS.ino]
2021-12-14 Added code to display battery level on the display
2021-12-14 Added delay in voltage read to allow analogRead to consistently get a reading
2021-12-14 Refactoring to improve battery display performance
2021-12-16 Battery level now shown as a % with charging and lo battery notices
2021-12-20 Updated 3d printed keypad cases with supports and deeper screw holes
    [LNURLPoS case top.3mf, LNURLPoS case top.stl]
2021-12-20 Added LilyGo T-Display Keyboard cases
    [LilyGo keyboard case bottom.3mf, LilyGo keyboard case top.3mf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]
2021-12-20 Added readme for LilyGo T-Display Keyboard case
2021-12-22 Put satoshigo defaults back in place and updated defaults for 30 second sleep mode and no battery level display
2021-12-22 Added lilygo keyboard case stand
    [Stand.3mf]
2021-12-22 Updated lilygo keyboard case stand to add extra support. Prevents flex
    [Stand.3mf]
2021-12-23 Bugfix to support "sats" instead of "sat" as currency name
    [LNURLPoS.ino]
2021-12-27 Removed pin2 output
    Not sure why pin 2 was set to output
2022-03-14 Updated 3d printed case files. Added stl with supports for membrane keypad case and larger screen hole for iffy lilygo TTGO boards
    [LNURLPoS case bottom.3mf, LNURLPoS case top.3mf, LNURLPoS case top.stl]
2022-03-14 Added default settings for arduino sketch
